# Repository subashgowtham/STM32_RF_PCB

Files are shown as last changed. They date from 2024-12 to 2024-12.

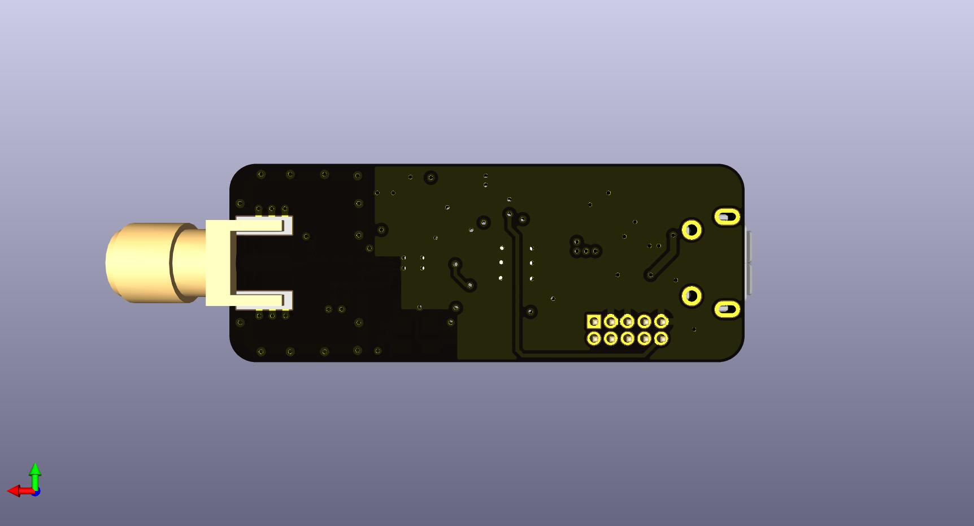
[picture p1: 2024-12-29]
MISC/3d_back.jpg

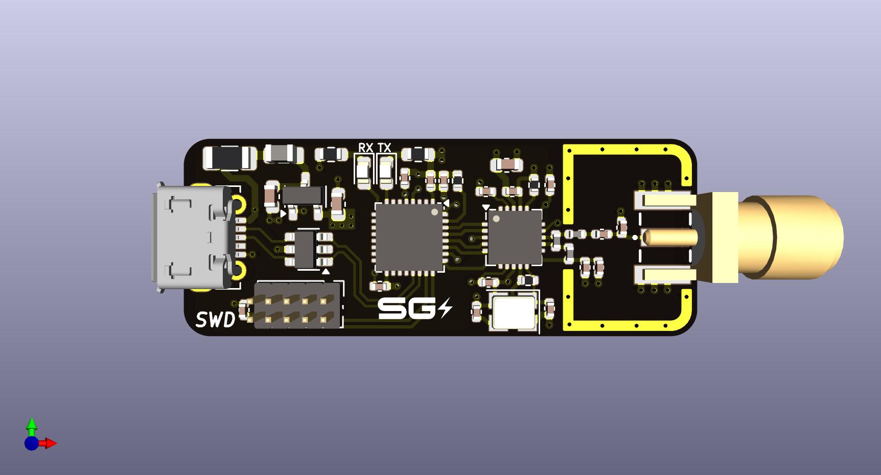
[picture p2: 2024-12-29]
MISC/3d_front.jpg

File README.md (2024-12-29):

# 4-Layer RF STM32 PCB Design
## Overview
This repository contains the design files for a 4-layer PCB featuring an STM32 microcontroller and RF components. The design is optimized for signal integrity and efficient RF performance, suitable for embedded applications requiring wireless communication.
## Layer Stackup
1. **Top Layer**: Signal traces and critical RF components.
2. **Inner Layer 1**: Ground plane for noise isolation.
3. **Inner Layer 2**: Power plane for stable power distribution.
4. **Bottom Layer**: Signal traces and supplementary components.

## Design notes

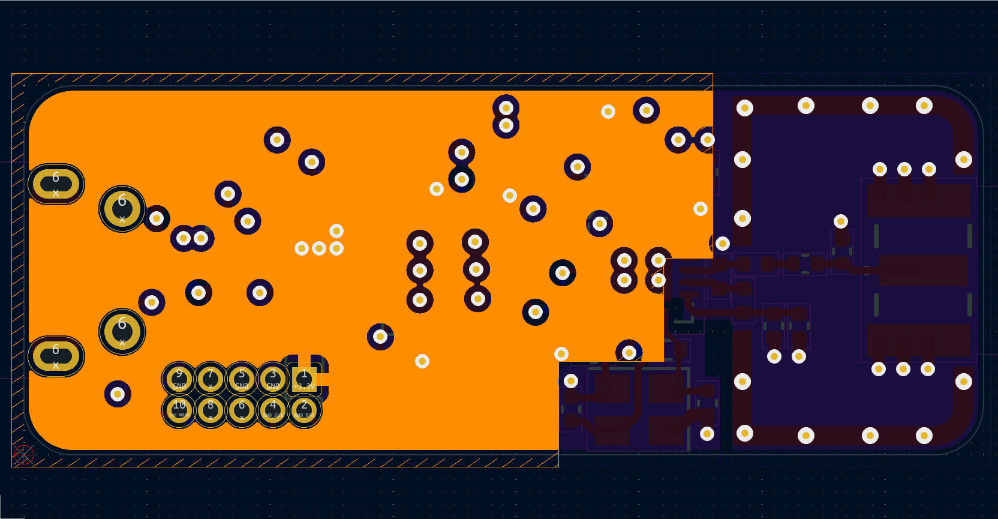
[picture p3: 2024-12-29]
MISC/L2.png

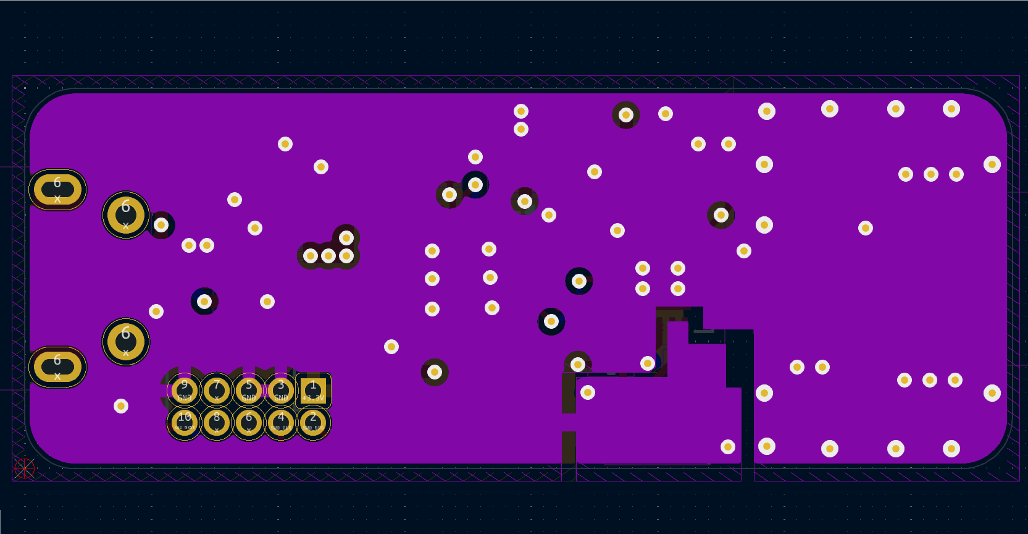
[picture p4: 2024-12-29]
MISC/L1.png

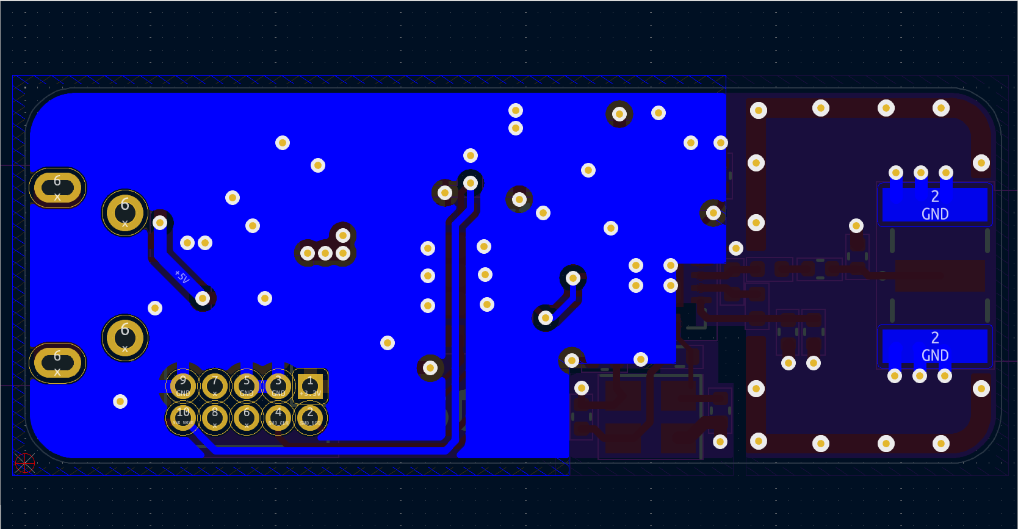
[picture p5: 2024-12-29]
MISC/bottom.png

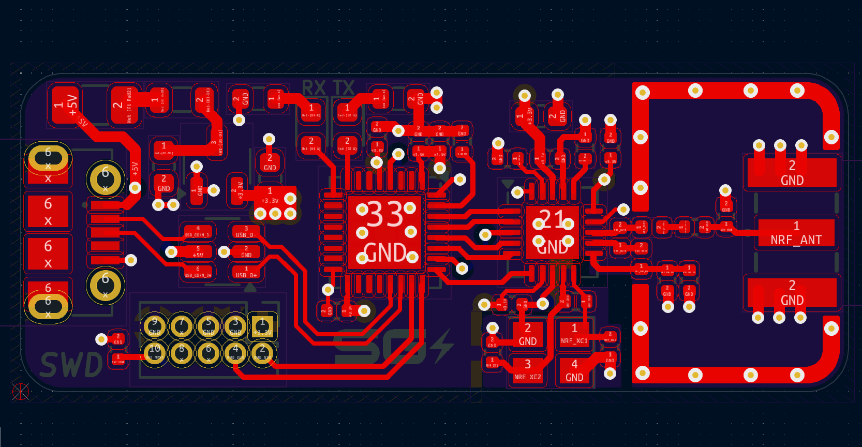
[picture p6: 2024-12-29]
MISC/front.png

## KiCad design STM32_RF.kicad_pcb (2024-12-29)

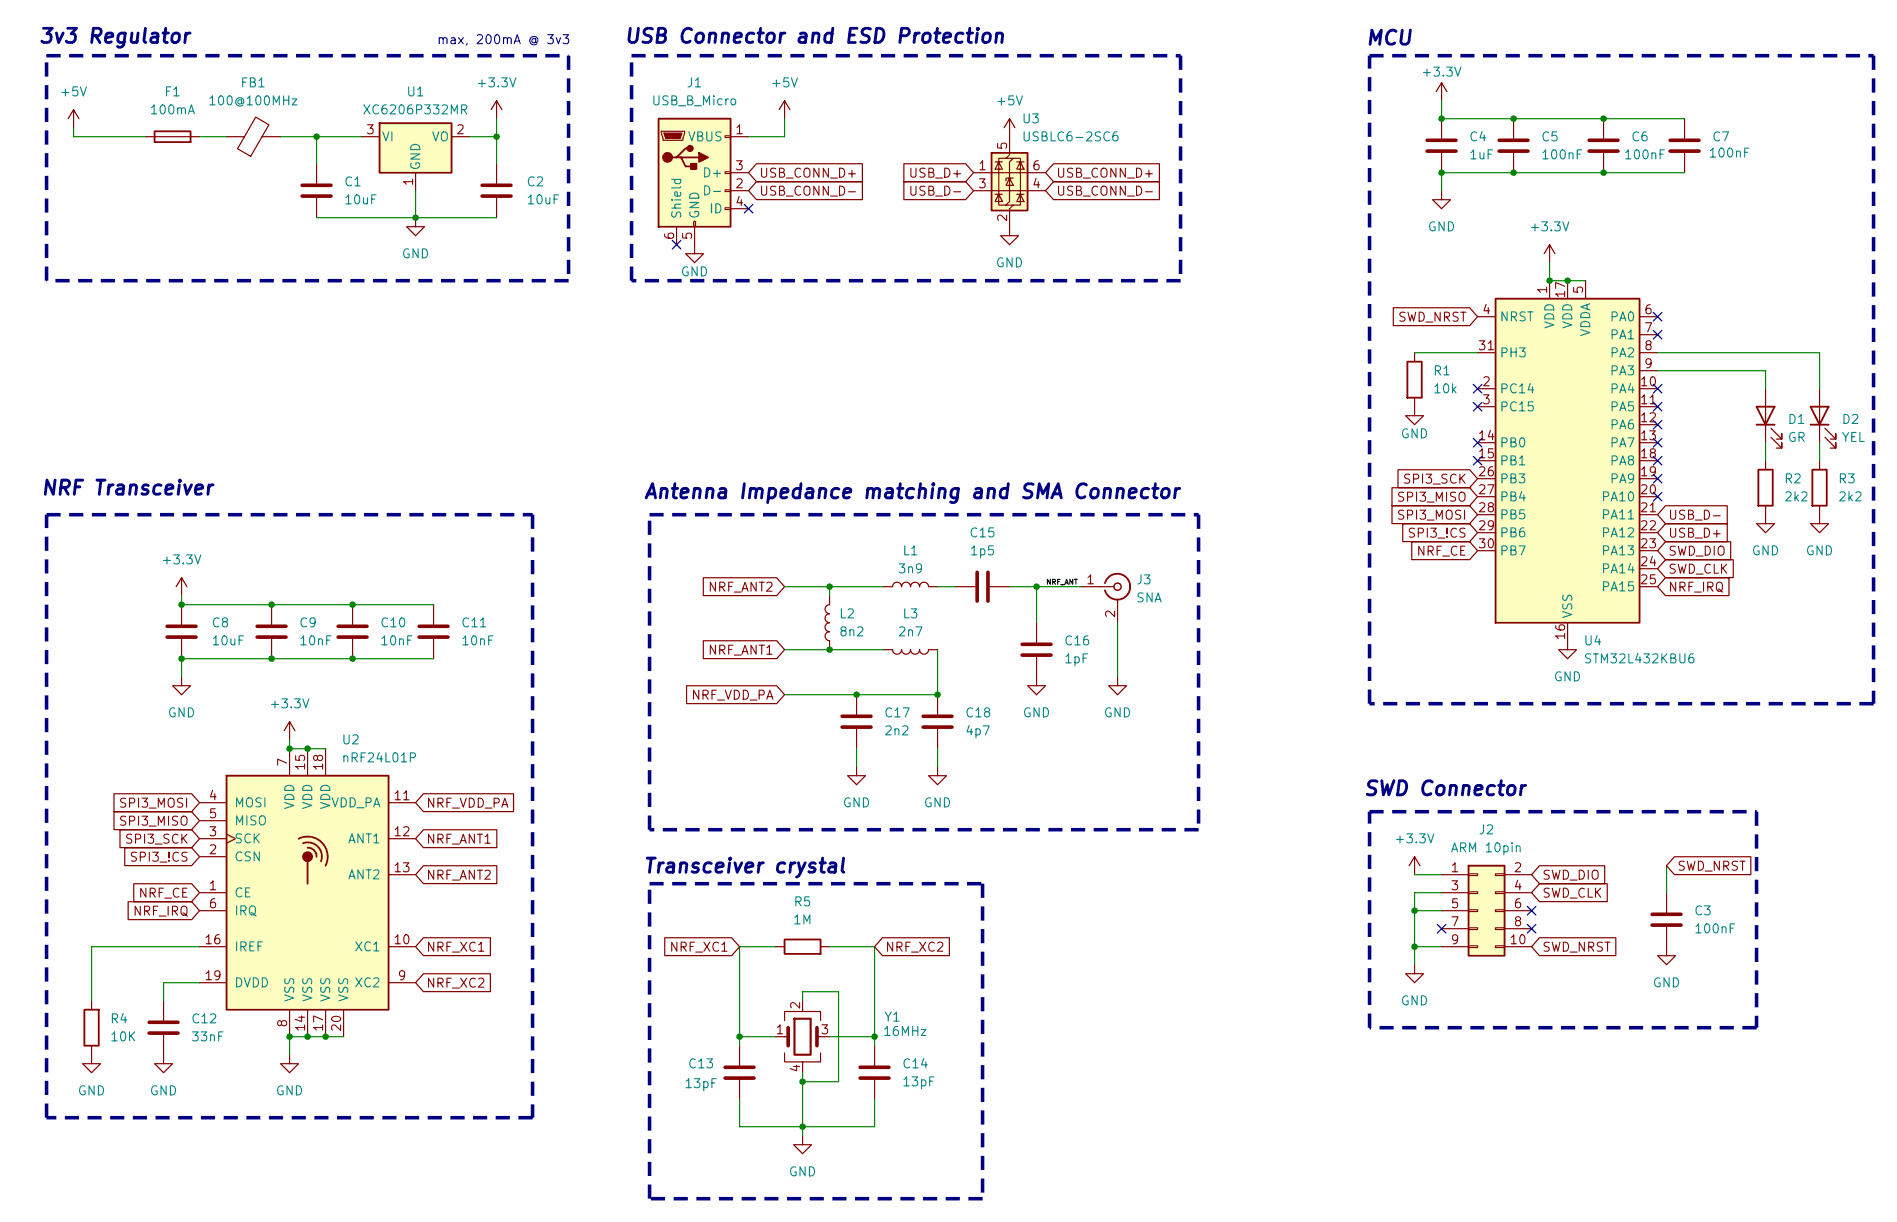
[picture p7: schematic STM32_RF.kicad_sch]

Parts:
C1, C2: 10uF; C_0603_1608Metric
C3, C5, C6, C7: 100nF; C_0402_1005Metric
C4: 1uF; C_0402_1005Metric
C8: 10uF; C_0201_0603Metric
C9, C10, C11: 10nF; C_0402_1005Metric
C12: 33nF; C_0402_1005Metric
C13, C14: 13pF; C_0402_1005Metric
C15: 1p5; C_0402_1005Metric
C16: 1pF; C_0402_1005Metric
C17: 2n2; C_0402_1005Metric
C18: 4p7; C_0402_1005Metric
D1: GR; LED_0603_1608Metric
D2: YEL; LED_0603_1608Metric
F1: 100mA; Fuse_1206_3216Metric
FB1: 100@100MHz; L_0805_2012Metric
J1: USB_B_Micro; USB_Micro-B_Molex-105017-0001
J2: ARM 10pin; PinHeader_2x05_P1.27mm_Vertical
J3: SNA; SAMTEC_SMA-J-P-H-ST-EM1
L1: 3n9; L_0402_1005Metric
L2: 8n2; L_0402_1005Metric
L3: 2n7; L_0402_1005Metric
R1: 10k; R_0402_1005Metric
R2, R3: 2k2; R_0603_1608Metric
R4: 10K; R_0402_1005Metric
R5: 1M; R_0402_1005Metric
U1: XC6206P332MR; SOT-23-3
U2: nRF24L01P; QFN-20-1EP_4x4mm_P0.5mm_EP2.5x2.5mm
U3: USBLC6-2SC6; SOT-23-6
U4: STM32L432KBU6; QFN-32-1EP_5x5mm_P0.5mm_EP3.45x3.45mm
Y1: 16MHz; Crystal_SMD_3225-4Pin_3.2x2.5mm

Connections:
+3.3V: C2.1, C4.1, C5.1, C6.1, C7.1, C8.1, C9.1, C10.1, C11.1, J2.1, U1.2 (VO), U2.7 (VDD), U2.15 (VDD), U2.18 (VDD), U4.1 (VDD), U4.5 (VDDA), U4.17 (VDD)
+5V: F1.1, J1.1 (VBUS), U3.5 (VBUS)
/NRF_ANT: C15.2, C16.1, J3.1 (In)
GND: C1.2, C2.2, C3.2, C4.2, C5.2, C6.2, C7.2, C8.2, C9.2, C10.2, C11.2, C12.2, C13.1, C14.2, C16.2, C17.2, C18.2, J1.5 (GND), J2.3, J2.5, J2.9, J3.2 (Ext), R1.2, R2.2, R3.2, R4.1, U1.1 (GND), U2.8 (VSS), U2.14 (VSS), U2.17 (VSS), U2.20 (VSS), U2.21, U3.2 (GND), U4.16 (VSS), U4.32 (VSS), U4.33 (VSS), Y1.2, Y1.4
NRF_ANT1: L2.1, L3.2, U2.12 (ANT1)
NRF_ANT2: L1.1, L2.2, U2.13 (ANT2)
NRF_CE: U2.1 (CE), U4.30 (PB7)
NRF_IRQ: U2.6 (IRQ), U4.25 (PA15)
NRF_VDD_PA: C17.1, C18.1, L3.1, U2.11 (VDD_PA)
NRF_XC1: C13.2, R5.1, U2.10 (XC1), Y1.1
NRF_XC2: C14.1, R5.2, U2.9 (XC2), Y1.3
unnamed: C15.1, L1.2
unnamed: D1.2 (A), U4.9 (PA3)
unnamed: D1.1 (K), R2.1
unnamed: D2.2 (A), U4.8 (PA2)
unnamed: D2.1 (K), R3.1
unnamed: F1.2, FB1.1
unnamed: C1.1, FB1.2, U1.3 (VI)
unnamed: C12.1, U2.19 (DVDD)
unnamed: R4.2, U2.16 (IREF)
unnamed: R1.1, U4.31 (PH3)
SPI3_!CS: U2.2 (CSN), U4.29 (PB6)
SPI3_MISO: U2.5 (MISO), U4.27 (PB4)
SPI3_MOSI: U2.4 (MOSI), U4.28 (PB5)
SPI3_SCK: U2.3 (SCK), U4.26 (PB3)
SWD_CLK: J2.4, U4.24 (PA14)
SWD_DIO: J2.2, U4.23 (PA13)
SWD_NRST: C3.1, J2.10, U4.4 (NRST)
USB_CONN_D+: J1.3 (D+), U3.6 (I/O1)
USB_CONN_D-: J1.2 (D-), U3.4 (I/O2)
USB_D+: U3.1 (I/O1), U4.22 (PA12)
USB_D-: U3.3 (I/O2), U4.21 (PA11)

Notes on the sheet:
MCU
SWD Connector
max, 200mA @ 3v3
USB Connector and ESD Protection
Antenna Impedance matching and SMA Connector
3v3 Regulator
Transceiver crystal
NRF Transceiver

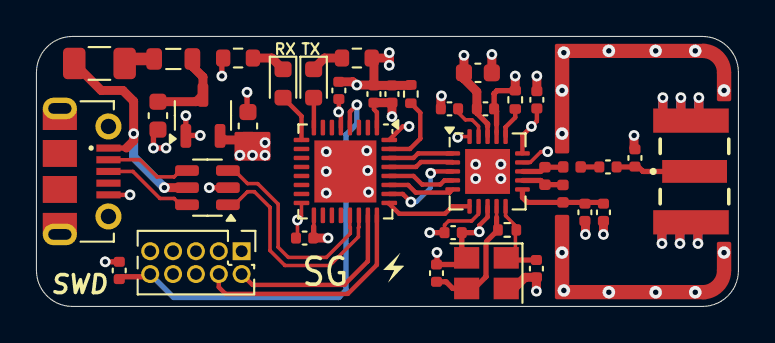
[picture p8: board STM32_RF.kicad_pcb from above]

Board: 4 copper layers, 39.0 x 15.0 mm, 38 parts (0 on the bottom side), 32 nets.
